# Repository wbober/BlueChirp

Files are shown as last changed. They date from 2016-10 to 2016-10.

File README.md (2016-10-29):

BlueChirp!
==========

A soil moisture sensor based on nRF52. Uses capacitive sensing for measurements
and Bluetooth Low Energy to send the readings.

The is work in progess. PCB is done and ordered, firmware yet to come.

Based on Chirp! designed by Albertas Mickėnas. Find out more here:
https://github.com/Miceuz/PlantWateringAlarm
https://wemakethings.net/chirp/

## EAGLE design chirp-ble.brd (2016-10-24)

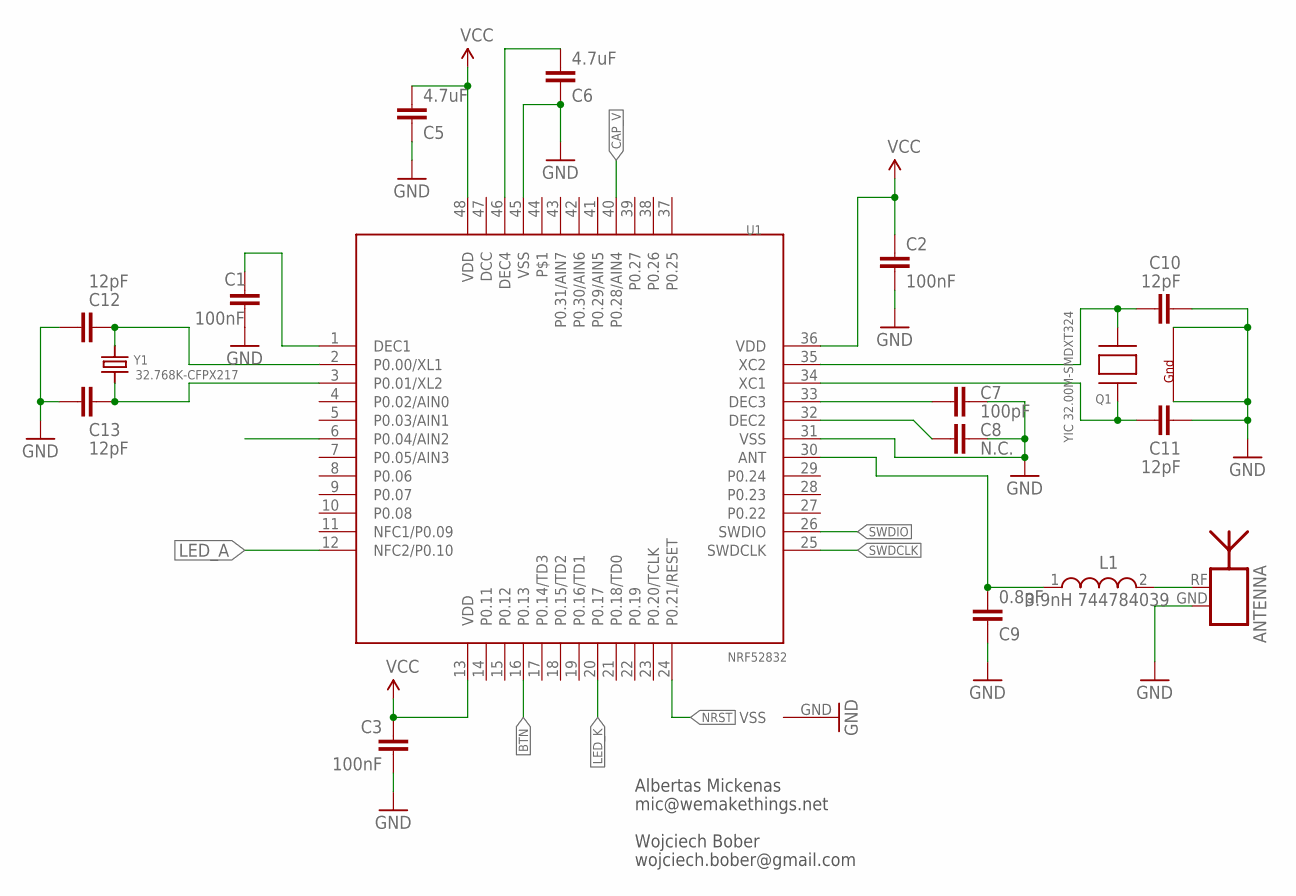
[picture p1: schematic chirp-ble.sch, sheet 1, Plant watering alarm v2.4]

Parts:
ANTENNA: ANTENNA_1RIGHT; SWRA117D_RIGHT
C1, C2, C3: 100nF; C0402
C5, C6: 4.7uF; C0402
C7: 100pF; C0402
C8: N.C.; C0402
C9: 0.8pF; C0402
C10, C11, C12, C13: 12pF; C0402
L1: 3.9nH 744784039; WE-MK_0402
Q1: YIC 32.00M-SMDXT324; NX3225
U1: NRF52832; QFN48
Y1: 32.768K-CFPX217; ABS07

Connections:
ANT: C9.2, L1.1, U1.30 (ANT)
BTN: U1.16 (P0.13); also elsewhere on the board
CAP_V: U1.40 (P0.28/AIN4); also elsewhere on the board
CLK_OUT: U1.6 (P0.04/AIN2); also elsewhere on the board
DCC: U1.47 (DCC)
GND: ANTENNA.GND, C1.2, C2.2, C3.2, C5.1, C6.1, C7.2, C8.2, C9.1, C10.2, C11.2, C12.2, C13.1, Q1.2 (G2), Q1.4 (G1), U1.31 (VSS), U1.45 (VSS), U1.GND (VSS); also elsewhere on the board
LED_A: U1.12 (NFC2/P0.10); also elsewhere on the board
LED_K: U1.20 (P0.17); also elsewhere on the board
unnamed: C8.1, U1.32 (DEC2)
unnamed: C10.1, Q1.3 (X2), U1.35 (XC2)
unnamed: ANTENNA.RF, L1.2
unnamed: C11.1, Q1.1 (X1), U1.34 (XC1)
unnamed: C1.1, U1.1 (DEC1)
unnamed: C6.2, U1.46 (DEC4)
unnamed: C7.1, U1.33 (DEC3)
NRST: U1.24 (P0.21/RESET); also elsewhere on the board
P$1: U1.44
SWDCLK: U1.25 (SWDCLK); also elsewhere on the board
SWDIO: U1.26 (SWDIO); also elsewhere on the board
VCC: C2.1, C3.1, C5.2, U1.13 (VDD), U1.36 (VDD), U1.48 (VDD); also elsewhere on the board
Y1_M: C13.2, U1.3 (P0.01/XL2), Y1.1
Y1_P: C12.1, U1.2 (P0.00/XL1), Y1.2

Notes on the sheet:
Albertas Mickenas
mic@wemakethings.net
Wojciech Bober
wojciech.bober@gmail.com

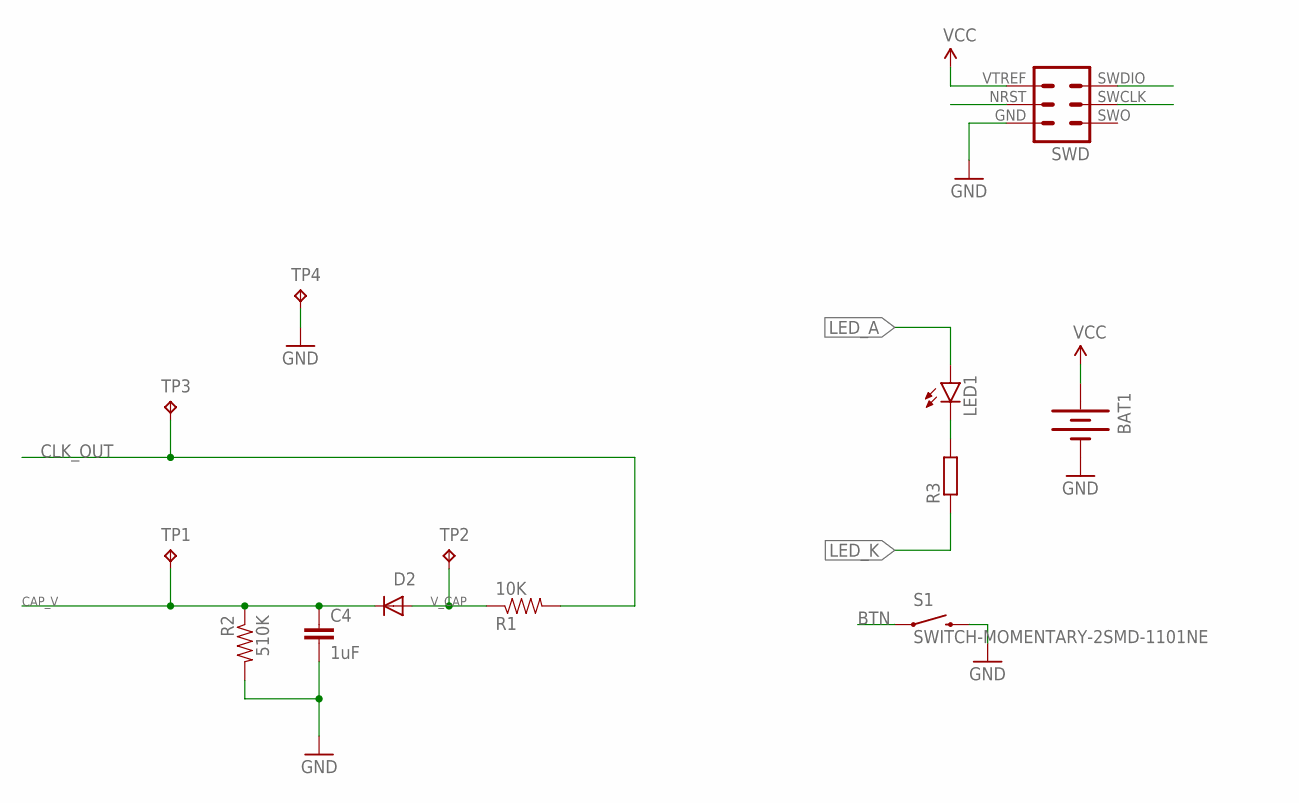
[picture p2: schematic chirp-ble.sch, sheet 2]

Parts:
BAT1: BATTERY12MM; BATTCON_12MM
C4: 1uF; 0603-CAP
D2: DIODE-SCHOTTKY_; SOD-523
LED1: LED0603; LED-0603
R1: 10K; 0603-RES
R2: 510K; 0603-RES
R3: R-EU_R0402; R0402
S1: SWITCH-MOMENTARY-2SMD-1101NE; TACTILE-SWITCH-1101NE
SWD: SWD; MA03-2
TP1, TP2, TP3, TP4: TPB1,27; B1,27

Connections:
BTN: S1.1; also elsewhere on the board
CAP_V: C4.1, D2.K (C), R2.1, TP1.TP; also elsewhere on the board
CLK_OUT: R1.2, TP3.TP; also elsewhere on the board
GND: BAT1.GND (-), C4.2, R2.2, S1.2, SWD.GND, TP4.TP; also elsewhere on the board
LED_A: LED1.A; also elsewhere on the board
LED_K: R3.1; also elsewhere on the board
unnamed: LED1.C, R3.2
NRST: SWD.NRST (NRESET); also elsewhere on the board
SWDCLK: SWD.SWCLK; also elsewhere on the board
SWDIO: SWD.SWDIO; also elsewhere on the board
VCC: BAT1.PWR@1 (+), BAT1.PWR@2 (+), SWD.VTREF; also elsewhere on the board
V_CAP: D2.A, R1.1, TP2.TP

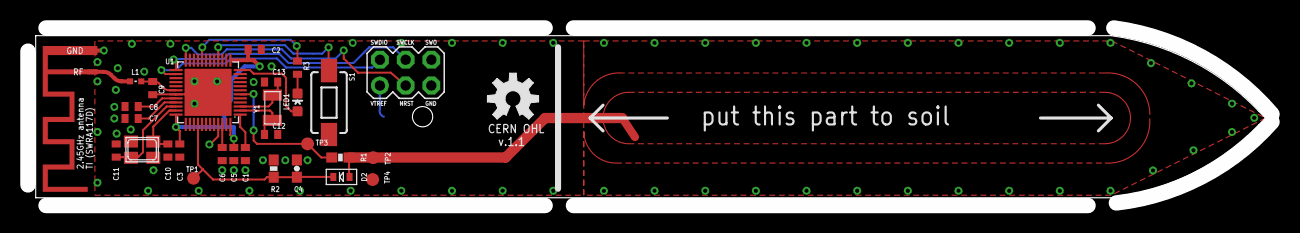
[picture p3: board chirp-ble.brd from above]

Board: 2 copper layers, 122.8 x 17.5 mm, 30 parts (1 on the bottom side), 22 nets.

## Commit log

2015-11-09 Fully routed
    [chirp-ble.brd, chirp-ble.sch]
2015-11-09 DRC and ERC
    [chirp-ble.brd, chirp-ble.sch]
2015-11-09 Added panel
    [chirp-ble-panel.brd, chirp-ble.brd]
2016-10-24 Changed min drill size to 0.4mm
    [chirp-ble-panel.brd, chirp-ble.brd, chirp-ble.sch]

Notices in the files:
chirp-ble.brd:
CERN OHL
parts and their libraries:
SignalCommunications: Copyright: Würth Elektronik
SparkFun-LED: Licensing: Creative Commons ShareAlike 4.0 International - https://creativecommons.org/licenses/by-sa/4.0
